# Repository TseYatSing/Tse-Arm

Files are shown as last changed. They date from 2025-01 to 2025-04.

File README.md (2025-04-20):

# Tse-M3CKA
> **我的机械臂**
>
>  视频介绍：[复刻开源机械臂](https://www.bilibili.com/video/BV1GM4m1R7kN/)
> 
>  视频介绍：[打印中](https://v.douyin.com/iyWBaaXT/)
> 
>  视频介绍：[是谁敲了一晚上的代码呀。是我呀累(ノへ`、)](https://v.douyin.com/iyWBVt3w/)
>
>  视频介绍：[上位程序搞定](https://v.douyin.com/aAHZoPsLHYs/)

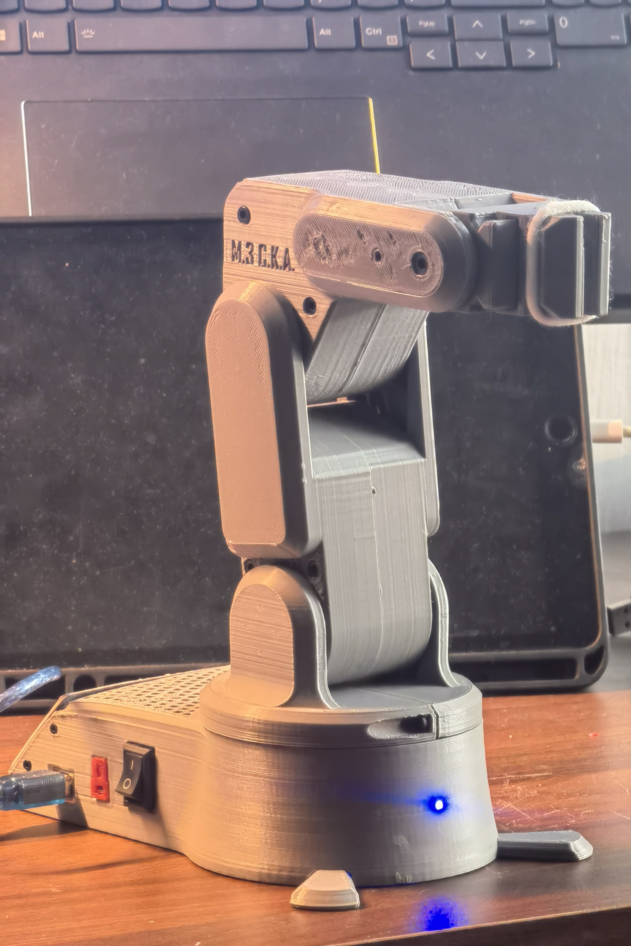
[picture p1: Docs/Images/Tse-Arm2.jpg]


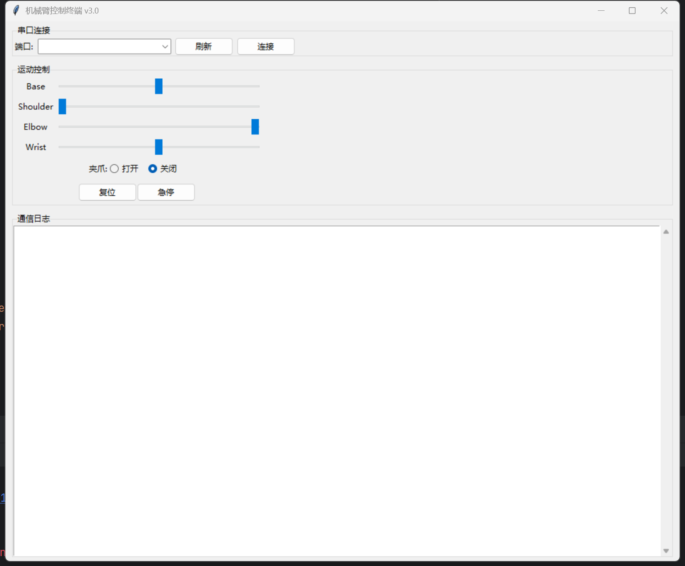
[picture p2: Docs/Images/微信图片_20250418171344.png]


> **感谢以下项目作者：**
>
> * [How to Build a 3D Printed Robot Arm Tutorial (Arduino Based)](https://youtube.com/watch?v=AIsVlgopqJc&si=mFCGv56T8LsnVQlr)

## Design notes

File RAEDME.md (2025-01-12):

# Tse-Arm
> **我的机械臂**
>
> 视频介绍：[【自制】我造了一台 钢 铁 侠 的 机 械 臂 ！【硬核】](https://www.bilibili.com/video/BV12341117rG)
>
> Video : [I made a DUMMY ROBOTIC ARM from scratch！ - YouTube](https://www.youtube.com/watch?v=F29vrvUwqS4)





### 资料说明（更新日期22-2-9）

* 已添加3D模型设计源文件。
* 已添加夹爪硬件设计文件和LED灯环PCB
* 已添加无线空间定位控制器PCB文件
* 已添加无线示教器Peak软硬件工程（作为submodule）
* 已添加REF的硬件设计文件
* 已添加DummyStudio上位机
* 已添加Dummy核心控制器的固件源代码（使用说明见后文）
* 已添加42步进电机驱动器硬件工程
* 已添加20步进电机驱动器硬件工程
* 已添加42/20步进电机驱动的固件源代码
* 已添加命令行调试工具reftool（基于odrivetool框架）
* 已添加便携手提箱的模型文件

> 这是视频中原版机械臂的完整设计方案，该方案成本和制作难度都比较高，因此想复现的同学建议再等等我后面会发布的**Dummy青春版**，该版本会有如下改进：
>
> 1. 整机重新设计结构，改用3D打印作为制造方案（原版为铝CNC），大幅降低制造成本
> 2. 采用我自己设计的小型摆线针轮减速器替代原版的谐波减速器，大幅降低零件成本
> 3. 所有软件和固件和原版通用，功能也完全一致
> 4. 添加我自己设计的PC端上位机和手机端APP（争取把用户初始化设置引导加进去）
> 5. 改进原版电机驱动器的走线方式，原版电源走线采用焊接的形式，不便于安装和拆卸，后面的青春版会使用4p接插件（电源+CAN总线）连接
> 6. 整机成本争取做到2000以内
> 7. **最重要的，会找人出一个保姆级的视频教程！**

## 关于结构设计

我视频中原版设计使用的`步进电机`+Harmonic的`谐波减速模组`，其中后者成本较高（我买的二手大概是600元一个），因此为了能让大家尽量复现本项目，我后期会添加一个`自制摆线针轮减速器`+`3D打印`的低成本方案。

> 目前摆线减速器已经设计好了正在验证，预期会使用PC（或者亚克力）切割结合3D打印制作，精度有所下降但是功能都保持不变，整机硬件成本希望控制在2000元以内。

设计好的摆线减速器见我的另一个仓库：[peng-zhihui/CycloidAcuratorNano ](https://github.com/peng-zhihui/CycloidAcuratorNano)



## 关于电路模块

电路为了实现主要的机械臂运动控制功能其实核心就4块板子：

* REF核心板
* REF底板（也就是机械臂底座里面的控制器电路板）
* 步进电机驱动
* Peak示教器

其中前两者和Peak我都开源了，步进驱动设计的时候参考了： https://github.com/unlir/XDrive 这个项目，这是我一个朋友开源的闭环驱动，基于STM32。该驱动分为开源版和闭源版，闭源版基于分立MOSFET性能极其强劲且功能很完善，开源版用的ADC+斩波驱动芯片，具备基础功能，不带CAN协议。

我重新设计了驱动器的PCB电路（本项目分别用到20、42步进，57的文件只是供大家扩展使用），添加了CAN总线的硬件支持，也对原版核心代码进行了完全重构，**提供编译好的二进制文件可以直接烧录：**



**主要改进如下：**

1. 使用C++11重构了代码，引入很多高级语言特性，同时底层部分用C混编，不影响代码性能
2. 对硬件依赖完全解耦了，可以方便以后移植到其他平台的MCU，去除了冗余代码代码也结构化逻辑更加清晰
3. 添加了CAN协议和UART协议的自定义模板
4. 添加了模拟EEPROM的参数储存，可以断电保存数据
5. 添加了任意位置设置为零点，且保证双向半圈内归零（而不是单向归零）
6. 完全兼容STM32-HAL库，可以使用STM32CubeMX直接生成配置代码
7. 其他改进，大家二次开发仅需关注UserApp文件夹下的文件即可

Ctrl-Step驱动的使用方式比较简单，下载好固件后，第一次上电电机会进行编码器校准，如果成功则下次上电后按下按键1会进入闭环模式，通过CAN或者串口发送指令即可控制电机，关于指令的说明见源代码`UserApp`文件夹的`interface_can.cpp`和`interface_uart.cpp`：



> 其他按键的作用：
>
> * 同时按住两个按键上电，会自动进行编码器校准，如果首次校准失败可以通过这个方式重新校准
> * 短按按键1在**使能闭环/失能闭环**间切换
> * 长按按键1板子重启
> * 短按按键2清除堵转保护
> * 长按按键2将目标值归零（比如如果是在位置模式那位置会归零）
>
> 其他的功能要通过代码或者通信协议设置，比如设置**home零点**、**PID参数**、CAN节点ID、**各种运动参数**等等，可以自己研究代码。

当然另一种方式是大家也可以自行使用GRBL类的驱动器改装用来驱动本机械臂，这样方案的问题在于，grbl固件耦合性比较强（毕竟不是针对机械臂而是CNC类应用设计的）不便于扩展，另外脉冲形式的控制方式使得走线极其不优雅（每一个关节都要单独拉`step/dir`线到控制器，导致最后几个关节走线很长）。

而我用一体闭环的方式则可以以串联的形式把所有电机连起来即可，走CAN总线使得整体走线只需要四根线（电源正负两根，CAN信号线两根），此外总线模型使得电机可以工作在`力矩`、`速度`、`位置`、`轨迹`模式下，而脉冲模式只能工作在位置和轨迹模式，无法进行复杂控制。

**Peak的话我之前已经软硬件都开源了，可以去SubModules文件夹里面看那边的README说明。**

## 关于核心固件

这个机械臂的固件核心就是运动学姿态解算，~~这块我还在整理，后面会封装得更完善一些进行开源~~，**已开源**，现在写死的很多参数会设计成可配置的，**方便大家用本项目学习完后迁移到自己设计的机械臂中**；同时我把固件从LiteOS框架移植到大家更熟悉的FreeRTOS，方便做二次开发。

**REF的固件使用说明：**

固件主要包括几大功能模块：

* BSP驱动：板载的各种硬件驱动比如OLED、IMU、LED、蜂鸣器、非易失储存等等
* 3rdParty库：包括U8G2的图形库和Fibre的序列化/反序列化库
* Core：ST官方的HAL库
* Driver：ARM的CMSIS驱动
* Midwares：FreeRTOS支持包
* Robot：核心机器人库，包括各种算法和驱动代码
* UserApp：上层应用，可以基于我提供的API接口自行开发其他应用

> * 其中OLED使用Arduino的U8G2库移植而来，可以方便地现实各种调试和系统信息，另外由于STM32的硬件I2C又BUG这里使用了软件I2C驱动屏幕，实测帧率比硬件I2C更高。

`DummyRobot`类是Dummy的完整定义所在，初始化的时候需要设置好**步进电机驱动的信息**以及**自身的DH参数**：



其中驱动器信息包含：CAN节点ID、**是否反向**、减速器的减速比、**运动限制范围**。

而DH参数的含义如下：



机械臂的构型需要满足Pieper判据（机器人的三个相邻关节轴交于一点或三轴线平行），才能得出解析解，所以大家可以根据Dummy的结构进行修改，然后自己替换DH参数即可以移植我的代码。

> 关于位置的记忆，和上电零点校准：
>
> **由于绝对值编码器的位置只在一圈内有效，工业机械臂经过减速后为了获取绝对位置一般是做输出端编码，但是这样精度就降低了30倍（减速比），所以更合理的是做`双编码器`或者低`功耗编码器+电池`；而我这个项目中双编码器影响结构紧凑设计，所以用了更巧妙的方式：利用电机驱动的电流环控制上电后进行低力矩的无零点定向运动，碰到机械臂限位之后确认粗零点（无限位开关归零），然后根据单圈绝对值编码器的位置精调零点。这个方式的零点是没有误差的，而且几乎不受加工精度影响，因为在12度（360/30）内都是绝对值编码器的有效精度范围。**

**Peak的固件说明：**

Peak基于X-Track项目，大家可以去Peak仓库查看。

## 关于上位机

视频中的软件仿真基于RoboDK，我在视频中开发了连接Dummy的Driver（驱动部分官方document有介绍的，原版是基于TCP网络接口，我修改成了串口并兼容dummy的协议）。不过由于这个软件是收费的，因此我也基于Unity3D开发了自己的上位机，已经发布在仓库。

上位机目前暂时没有计划开源，因为还有很多功能要添加，我也是希望最后能做成一个类似RoboDK的通用软件，大家以后自己做机械臂也能用上，当然软件肯定会是免费的。

## 关于控制算法

首先运动学部分是已经实现了的，正逆解都是传统DH参数计算的，正解（关节角求末端位姿）是唯一解比较好办，逆解（末端位姿求关节角）的话会涉及多解（一般是8个），我这里使用的算法是**求解上一姿态和目标姿态中6个关节变化最大角里面最小的那一组作为逆解采用的config**。这样可以保证机械臂始终以最小转角进行姿态切换。

然后关节角到电机驱动器输入信号的转换这一块，我使用的是梯形加减速曲线进行速度位置规划。举个例子在MoveJ指令中，当收到一个关节角运动指令，控制器会进行运动角度差分计算，得到6个运动差分角度，然后取6个差分角中最大的角θ，同时根据设置的JointSpeed参数计算运动θ角需要的时间（考虑上加减速），把这一时间作为其余5个电机的运动参数计算各自的加减速度&最高速度，然后6个电机根据计算的参数同步运动，就可以保证其同步性和流畅性了。

另外六个电机使用CAN总线连接，每个电机接受两个ID号的信息（自己的ID、0号ID），0号ID作为信息广播和同步用。电机接收到运动指令后将信息储存在影子寄存器中，待收到广播的同步信号后开始运动，这样能进一步保证电机同步性。

最后，动力学部分还在开发中，这块暂时没有完全实现。上**述的运动学和动力学算法都强烈建议去看一下《机器人学导论》这本书**，里面写得非常详细。

## 指令模式

Dummy固件支持三种不同的指令模式（指令可以由USB、串口、CAN接收），不同模式的特性有所区别，见下表：

| | 指令发送频率 | 指令执行方式 | 可被新指令打断 | 指令间停顿 | 适合场景 |
| --- | --- | --- | --- | --- | --- |
| SEQ（顺序指令） | 随机，低（<5Hz）  | FIFO队列依次执行 | 否 | 有 | 一次性发送几个关键点位姿，等待依次执行，可以确保关键点到达；但是由于关键点之间存在减速到0的过程所以存在一定停顿；适合场景例如**视觉抓取、码垛等应用**。 |
| INT（实时指令） | 随机，频率不限 | 指令覆盖，立即执行 | 是 | 无 | 用于实时控制，新指令会覆盖正在执行的指令得到立即响应；但是如果一次性发送一系列指令的话则效果会是只执行最后一条；适合场景例如**动作同步**。 |
| `ToDo`TRJ（轨迹跟踪） | 固定，高（200Hz） | 自动插值，固定周期执行 | 否 | 无 | 适合用于需要进行精确轨迹跟踪的应用，速度会放慢；示例场景比如**3D打印、雕刻、绘画等**。 |

---

> **感谢以下项目作者：**
>
> * [unlir/XDrive: Stepper motor with multi-function interface and closed loop function. 具有多功能接口和闭环功能的步进电机。 (github.com)](https://github.com/unlir/XDrive)

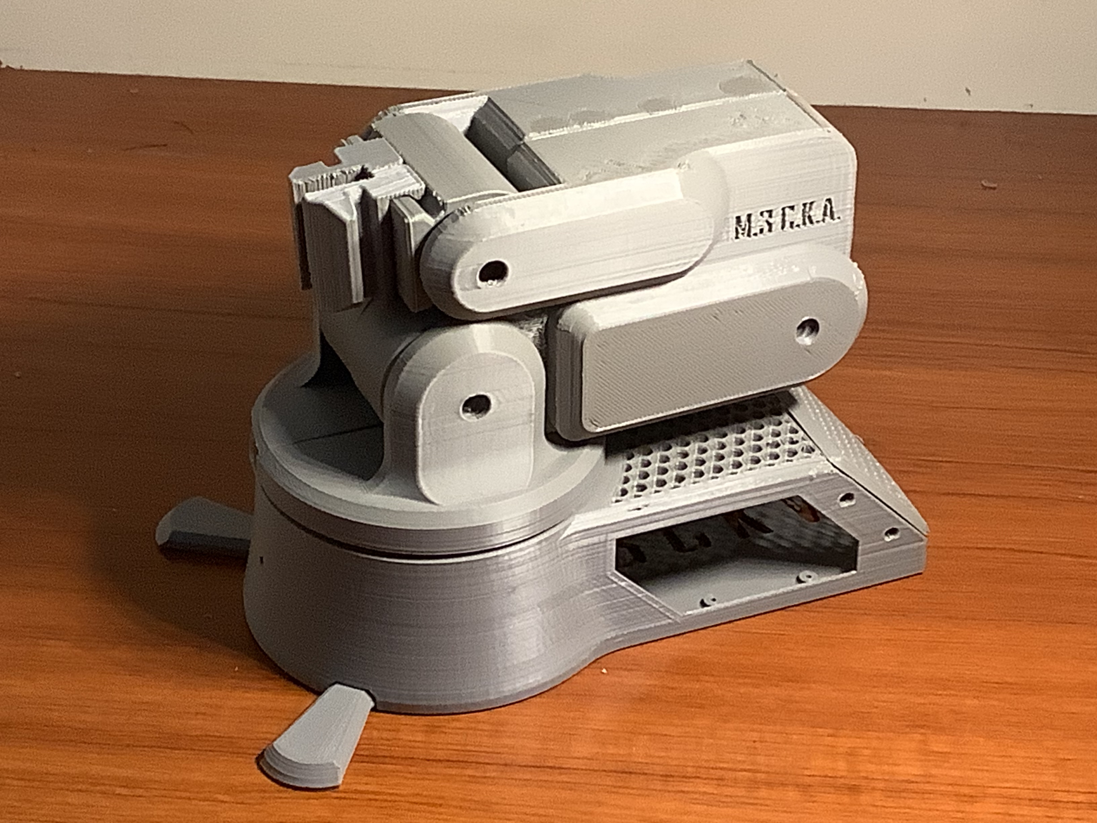
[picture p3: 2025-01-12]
Docs/Images/Tse-Arm1.jpg

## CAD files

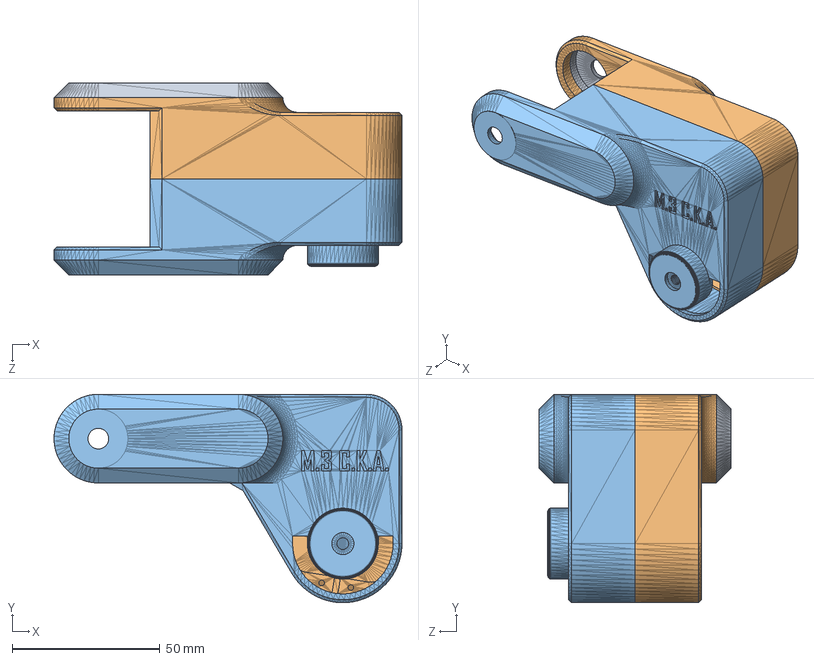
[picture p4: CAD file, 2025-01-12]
Model/F/F.SLDASM
117.7 x 70.5 x 65.1 mm
F1
F2
F2C

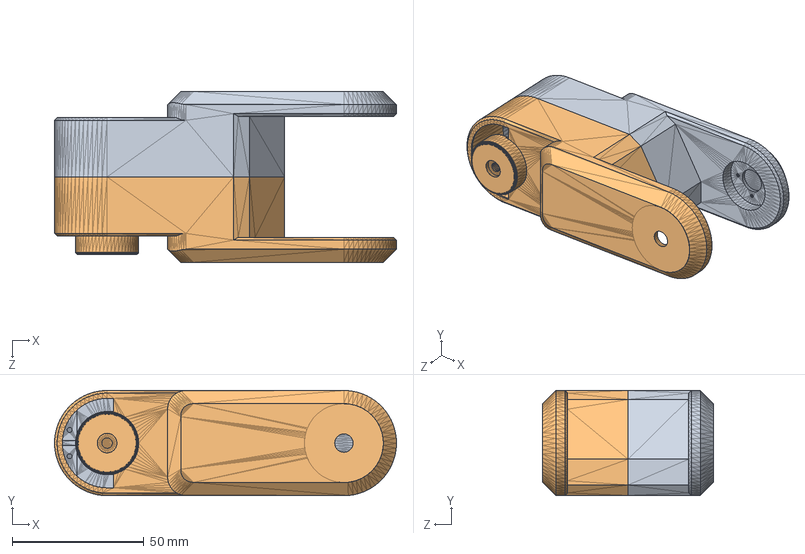
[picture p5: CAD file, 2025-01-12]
Model/M/M.SLDASM
130.0 x 39.9 x 65.1 mm
M1
M2

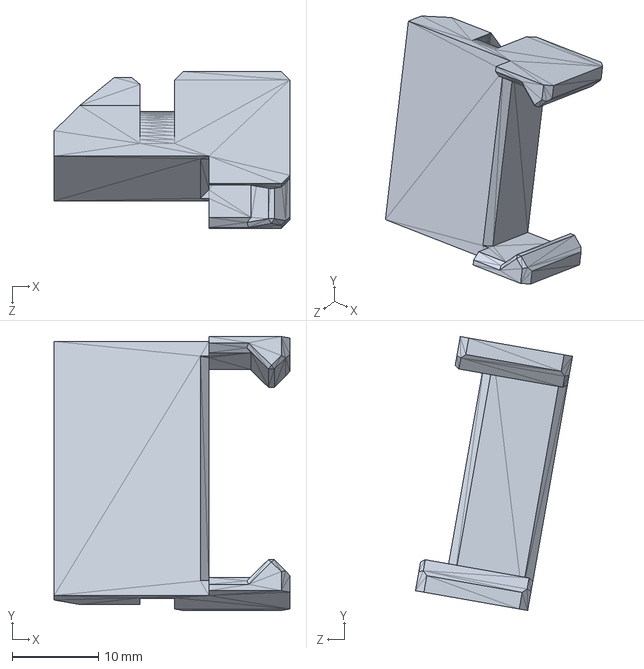
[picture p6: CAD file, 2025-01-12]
Model/G/G3.SLDPRT
27.4 x 31.8 x 18.3 mm

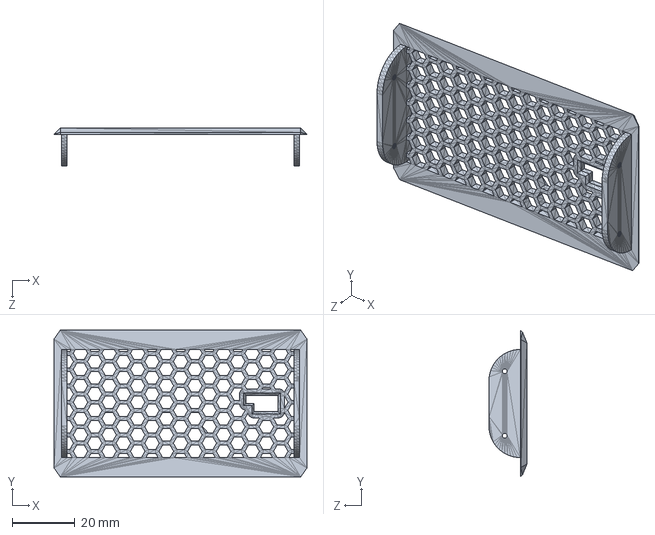
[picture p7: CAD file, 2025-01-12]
Model/MB/MB4.SLDPRT
80.5 x 46.7 x 12.1 mm

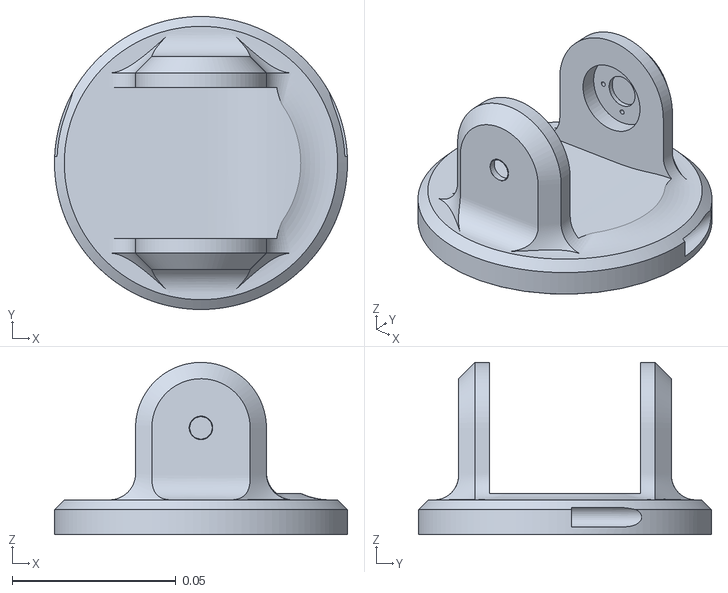
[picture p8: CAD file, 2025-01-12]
Model/URDF/robot arm.SLDASM/meshes/B_Link.STL
0.0895 x 0.0895 x 0.0526

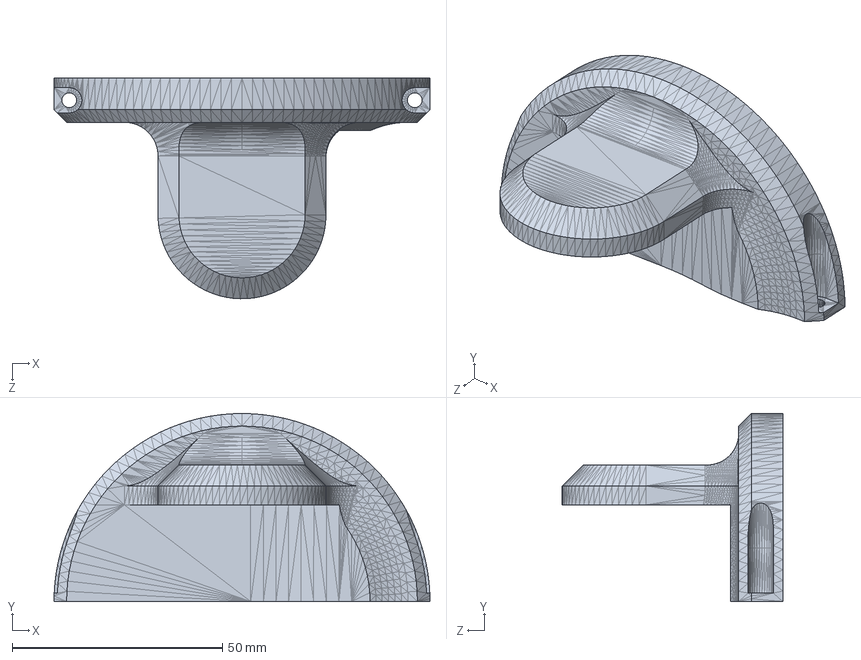
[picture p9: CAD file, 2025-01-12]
Model/B/B (2).SLDPRT
89.5 x 44.8 x 52.5 mm

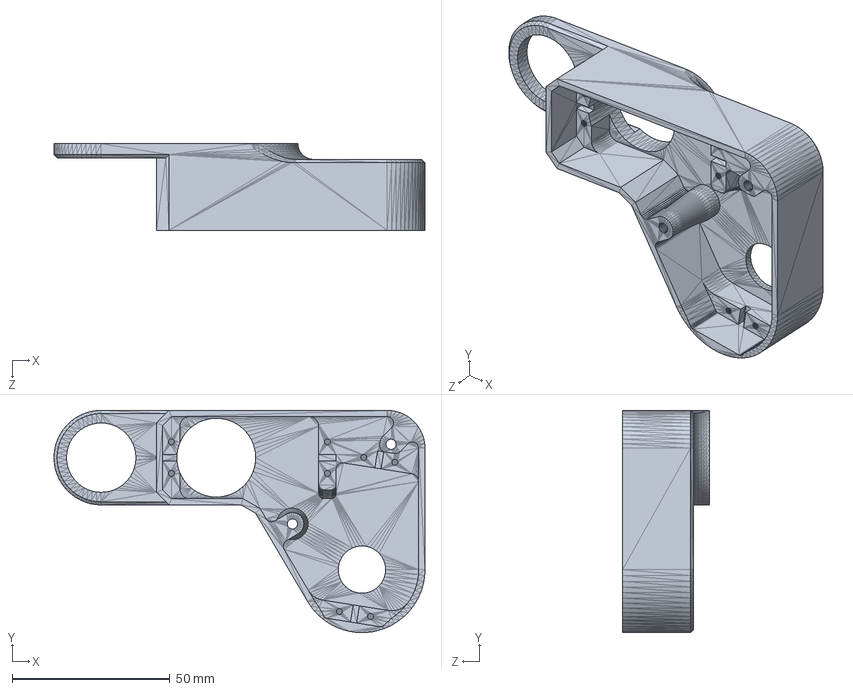
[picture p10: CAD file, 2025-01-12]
Model/F/F2.SLDPRT
117.7 x 70.5 x 27.5 mm

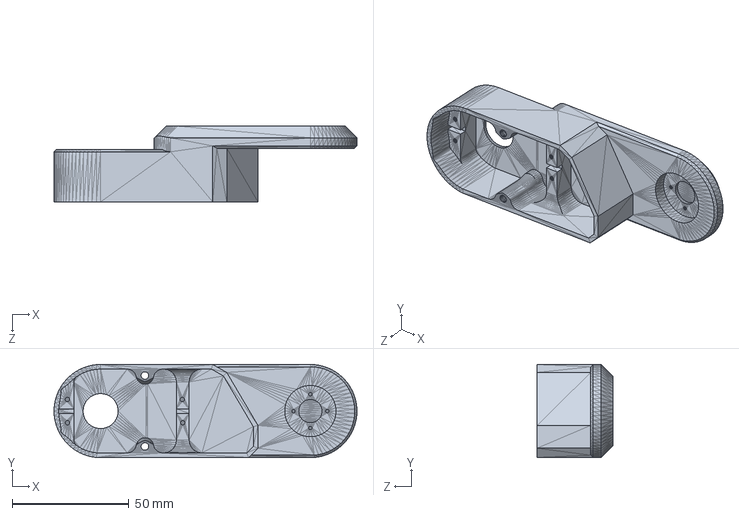
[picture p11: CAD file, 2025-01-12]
Model/M/M2.SLDPRT
130.0 x 39.9 x 32.5 mm

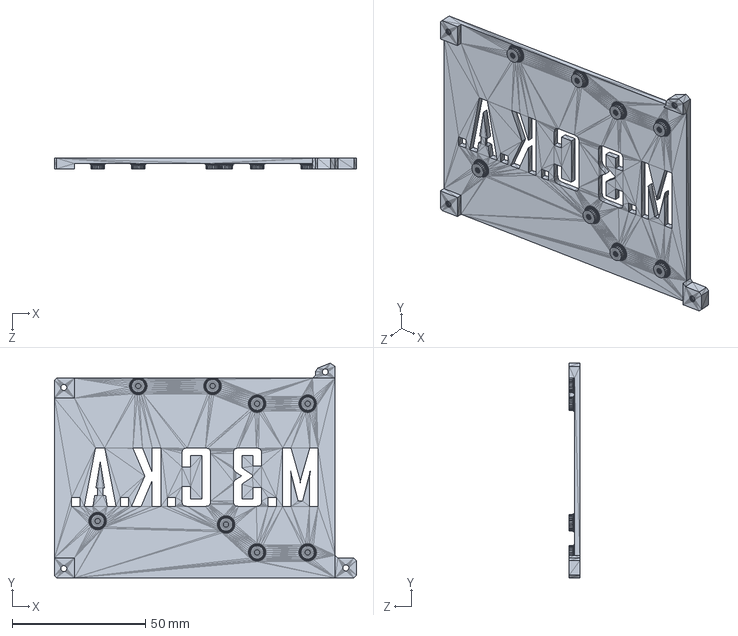
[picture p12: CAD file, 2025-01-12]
Model/MB/MB2.SLDPRT
113.5 x 80.7 x 4.00 mm

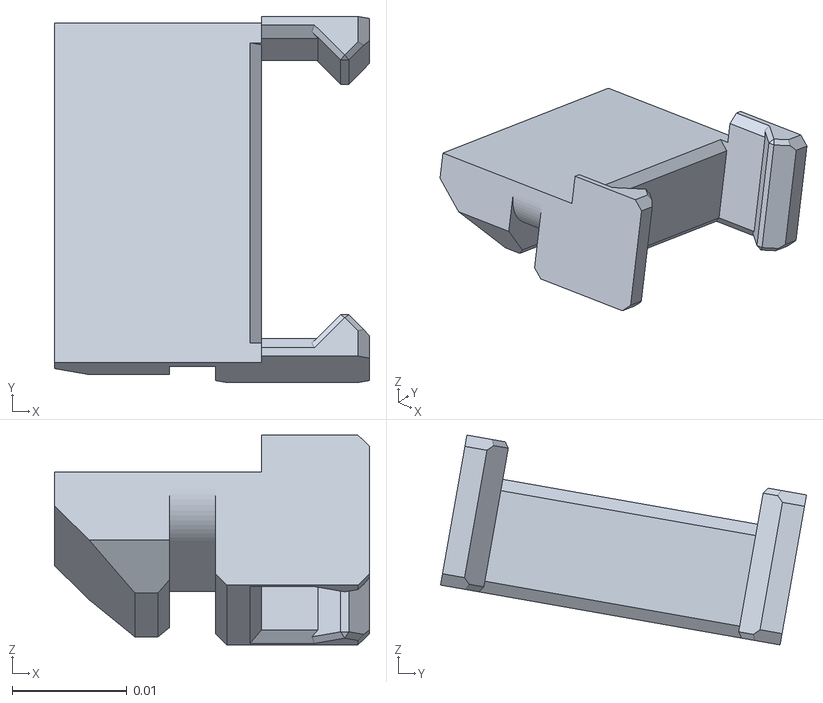
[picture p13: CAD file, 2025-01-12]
Model/URDF/robot arm.SLDASM/meshes/HR_Link.STL
0.0274 x 0.0318 x 0.0183

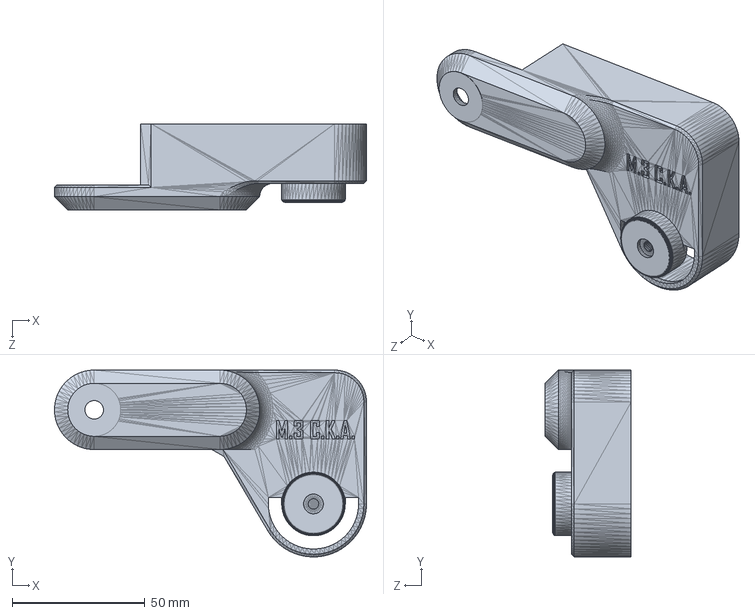
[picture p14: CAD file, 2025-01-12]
Model/F/F1.SLDPRT
117.7 x 70.5 x 32.6 mm

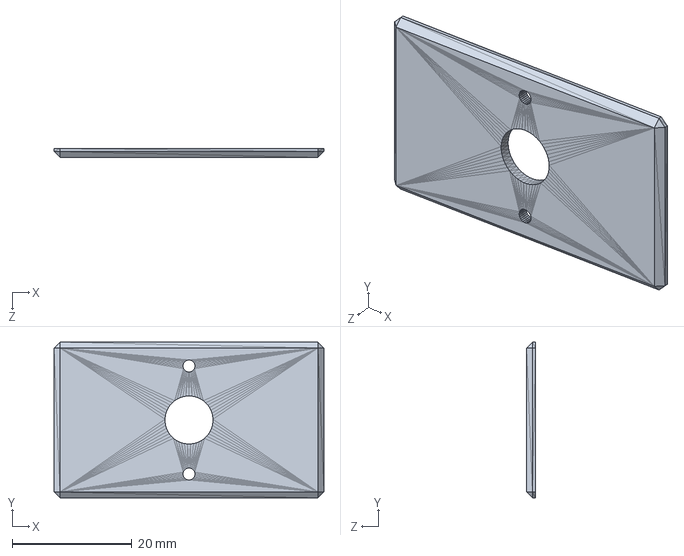
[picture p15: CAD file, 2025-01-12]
Model/G/G2.SLDPRT
45.0 x 26.0 x 1.50 mm

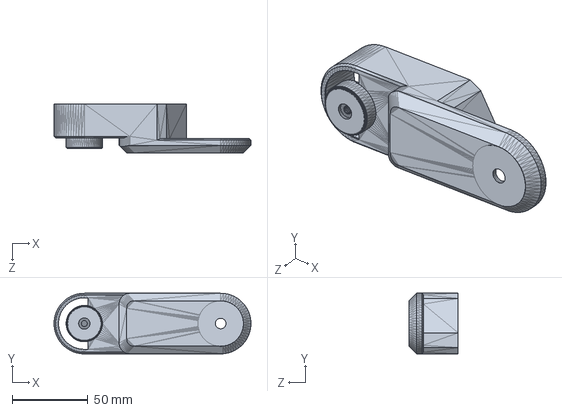
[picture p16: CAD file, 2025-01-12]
Model/M/M1.SLDPRT
130.0 x 39.9 x 32.6 mm

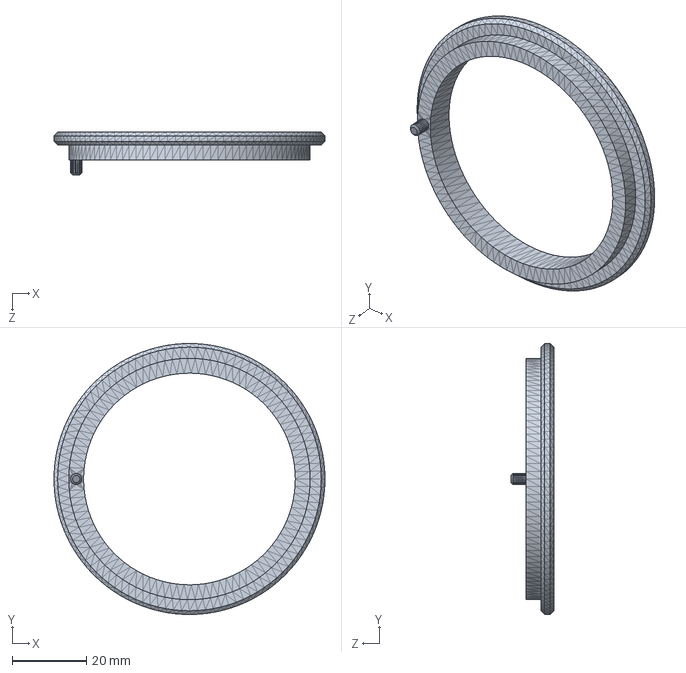
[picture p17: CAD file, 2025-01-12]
Model/MB/MB1R.SLDPRT
73.0 x 73.0 x 11.5 mm

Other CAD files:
Model/B/B (1).SLDASM
Model/G/G.SLDASM
Model/URDF/robot arm.SLDASM/meshes/S_Link.STL
Model/F/F2C.SLDPRT
Model/G/G1.SLDPRT
Model/G/G4.SLDPRT
Model/MB/MB3.SLDPRT
Model/URDF/robot arm.SLDASM/meshes/E_Link.STL
Model/URDF/robot arm.SLDASM/meshes/HL_Link.STL
Model/URDF/robot arm.SLDASM/meshes/W_Link.STL
Model/URDF/robot arm.SLDASM/meshes/base_link.STL

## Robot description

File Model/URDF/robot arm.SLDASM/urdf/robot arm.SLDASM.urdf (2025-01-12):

<?xml version="1.0" encoding="utf-8"?>
<!-- This URDF was automatically created by SolidWorks to URDF Exporter! Originally created by Stephen Brawner (brawner@gmail.com) 
     Commit Version: 1.6.0-4-g7f85cfe  Build Version: 1.6.7995.38578
     For more information, please see http://wiki.ros.org/sw_urdf_exporter -->
<robot name="robot arm.SLDASM">
  <link name="base_link">
    <inertial>
      <origin xyz="0.038474 0.047626 0.066497" rpy="0 0 0" />
      <mass value="0.014181" />
      <inertia ixx="5.6168E-06" ixy="-1.2686E-09" ixz="1.085E-09" iyy="1.3583E-05" iyz="-4.3104E-07" izz="8.9876E-06" />
    </inertial>
    <visual>
      <origin xyz="0 0 0" rpy="0 0 0" />
      <geometry>
        <mesh filename="package://robot arm.SLDASM/meshes/base_link.STL" />
      </geometry>
      <material name="">
        <color rgba="0.79216 0.81961 0.93333 1" />
      </material>
    </visual>
    <collision>
      <origin xyz="0 0 0" rpy="0 0 0" />
      <geometry>
        <mesh filename="package://robot arm.SLDASM/meshes/base_link.STL" />
      </geometry>
    </collision>
  </link>
  <link name="B_Link">
    <inertial>
      <origin xyz="0.00061683 0.0022099 0.013874" rpy="0 0 0" />
      <mass value="0.055527" />
      <inertia ixx="1.6319E-05" ixy="2.4099E-08" ixz="8.2856E-08" iyy="3.3446E-05" iyz="4.9691E-09" izz="3.086E-05" />
    </inertial>
    <visual>
      <origin xyz="0 0 0" rpy="0 0 0" />
      <geometry>
        <mesh filename="package://robot arm.SLDASM/meshes/B_Link.STL" />
      </geometry>
      <material name="">
        <color rgba="0.79216 0.81961 0.93333 1" />
      </material>
    </visual>
    <collision>
      <origin xyz="0 0 0" rpy="0 0 0" />
      <geometry>
        <mesh filename="package://robot arm.SLDASM/meshes/B_Link.STL" />
      </geometry>
    </collision>
  </link>
  <joint name="BJ" type="revolute">
    <origin xyz="0.038382 -0.10676 0.051092" rpy="0 0 1.5658" />
    <parent link="base_link" />
    <child link="B_Link" />
    <axis xyz="0 0 -1" />
    <limit lower="-1.57" upper="1.57" effort="100" velocity="2.01" />
  </joint>
  <link name="S_Link">
    <inertial>
      <origin xyz="0.064577 -0.0006428 -0.0044202" rpy="0 0 0" />
      <mass value="0.074894" />
      <inertia ixx="1.7741E-05" ixy="5.6338E-07" ixz="2.0818E-06" iyy="8.194E-05" iyz="1.0703E-08" izz="8.883E-05" />
    </inertial>
    <visual>
      <origin xyz="0 0 0" rpy="0 0 0" />
      <geometry>
        <mesh filename="package://robot arm.SLDASM/meshes/S_Link.STL" />
      </geometry>
      <material name="">
        <color rgba="0.79216 0.81961 0.93333 1" />
      </material>
    </visual>
    <collision>
      <origin xyz="0 0 0" rpy="0 0 0" />
      <geometry>
        <mesh filename="package://robot arm.SLDASM/meshes/S_Link.STL" />
      </geometry>
    </collision>
  </link>
  <joint name="SJ" type="revolute">
    <origin xyz="0.038382 -0.10676 0.063392" rpy="-1.5708 -1.5557 -1.5758" />
    <parent link="base_link" />
    <child link="S_Link" />
    <axis xyz="0 0 1" />
    <limit lower="-1.57" upper="1.57" effort="100" velocity="2.01" />
  </joint>
  <link name="E_Link">
    <inertial>
      <origin xyz="0.073989 0.047337 -0.017744" rpy="0 0 0" />
      <mass value="0.036475" />
      <inertia ixx="1.4964E-05" ixy="4.7351E-06" ixz="-1.6026E-06" iyy="3.0336E-05" iyz="4.1041E-07" izz="4.2075E-05" />
    </inertial>
    <visual>
      <origin xyz="0 0 0" rpy="0 0 0" />
      <geometry>
        <mesh filename="package://robot arm.SLDASM/meshes/E_Link.STL" />
      </geometry>
      <material name="">
        <color rgba="0.79216 0.81961 0.93333 1" />
      </material>
    </visual>
    <collision>
      <origin xyz="0 0 0" rpy="0 0 0" />
      <geometry>
        <mesh filename="package://robot arm.SLDASM/meshes/E_Link.STL" />
      </geometry>
    </collision>
  </link>
  <joint name="EJ" type="revolute">
    <origin xyz="0.03889 -0.20556 0.1525" rpy="1.5708 -0.012159 1.5658" />
    <parent link="base_link" />
    <child link="E_Link" />
    <axis xyz="0 0 0" />
    <limit lower="-1.57" upper="1.57" effort="100" velocity="2.01" />
  </joint>
  <link name="W_Link">
    <inertial>
      <origin xyz="0.023273 0.013 -0.014326" rpy="0 0 0" />
      <mass value="0.027884" />
      <inertia ixx="3.9584E-06" ixy="4.4613E-13" ixz="-4.748E-07" iyy="8.9096E-06" iyz="-3.5765E-13" izz="9.2469E-06" />
    </inertial>
    <visual>
      <origin xyz="0 0 0" rpy="0 0 0" />
      <geometry>
        <mesh filename="package://robot arm.SLDASM/meshes/W_Link.STL" />
      </geometry>
      <material name="">
        <color rgba="0.79216 0.81961 0.93333 1" />
      </material>
    </visual>
    <collision>
      <origin xyz="0 0 0" rpy="0 0 0" />
      <geometry>
        <mesh filename="package://robot arm.SLDASM/meshes/W_Link.STL" />
      </geometry>
    </collision>
  </link>
  <joint name="WJ" type="fixed">
    <origin xyz="0.01688 -0.2075 0.19376" rpy="1.6544 0 -0.0049831" />
    <parent link="base_link" />
    <child link="W_Link" />
    <axis xyz="0 0 0" />
    <limit lower="-1.57" upper="1.57" effort="100" velocity="2.01" />
  </joint>
  <link name="HL_Link">
    <inertial>
      <origin xyz="0.011436 0.015 0.0060195" rpy="0 0 0" />
      <mass value="0.004589" />
      <inertia ixx="4.3212E-07" ixy="6.3465E-15" ixz="5.8852E-09" iyy="2.305E-07" iyz="2.4915E-15" izz="5.9215E-07" />
    </inertial>
    <visual>
      <origin xyz="0 0 0" rpy="0 0 0" />
      <geometry>
        <mesh filename="package://robot arm.SLDASM/meshes/HL_Link.STL" />
      </geometry>
      <material name="">
        <color rgba="0.79216 0.81961 0.93333 1" />
      </material>
    </visual>
    <collision>
      <origin xyz="0 0 0" rpy="0 0 0" />
      <geometry>
        <mesh filename="package://robot arm.SLDASM/meshes/HL_Link.STL" />
      </geometry>
    </collision>
  </link>
  <joint name="HLJ" type="prismatic">
    <origin xyz="0.054975 -0.22936 0.22004" rpy="-1.5708 -0.083571 1.5658" />
    <parent link="base_link" />
    <child link="HL_Link" />
    <axis xyz="0 0 0" />
    <limit lower="0" upper="0.02" effort="100" velocity="2.01" />
  </joint>
  <link name="HR_Link">
    <inertial>
      <origin xyz="0.011436 0.015817 0.0085328" rpy="0 0 0" />
      <mass value="0.004589" />
      <inertia ixx="4.3212E-07" ixy="1.022E-09" ixz="5.7958E-09" iyy="2.4141E-07" iyz="6.1845E-08" izz="5.8124E-07" />
    </inertial>
    <visual>
      <origin xyz="0 0 0" rpy="0 0 0" />
      <geometry>
        <mesh filename="package://robot arm.SLDASM/meshes/HR_Link.STL" />
      </geometry>
      <material name="">
        <color rgba="0.79216 0.81961 0.93333 1" />
      </material>
    </visual>
    <collision>
      <origin xyz="0 0 0" rpy="0 0 0" />
      <geometry>
        <mesh filename="package://robot arm.SLDASM/meshes/HR_Link.STL" />
      </geometry>
    </collision>
  </link>
  <joint name="HRJ" type="prismatic">
    <origin xyz="0.018549 -0.22675 0.19105" rpy="1.7453 -0.083571 1.5658" />
    <parent link="base_link" />
    <child link="HR_Link" />
    <axis xyz="0 0 0" />
    <limit lower="-0.02" upper="0" effort="100" velocity="2.01" />
  </joint>
</robot>

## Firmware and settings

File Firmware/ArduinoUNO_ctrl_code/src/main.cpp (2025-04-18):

#include <Arduino.h>
#include <Adafruit_PWMServoDriver.h>

#define MIN_PULSE_WIDTH   500
#define MAX_PULSE_WIDTH   2500
#define PWM_FREQ          50
#define MAX_CMD_LENGTH    30

Adafruit_PWMServoDriver pwm = Adafruit_PWMServoDriver();

const uint8_t SERVO_PINS[5] = {15, 14, 13, 12, 11}; // BASE, SHOULDER, ELBOW, WRIST, GRIPPER

float angleToPulse(float angle) {
  angle = constrain(angle, 0.0, 180.0);
  return map(angle, 0.0, 180.0, MIN_PULSE_WIDTH, MAX_PULSE_WIDTH);
}

void setServoAngle(uint8_t servoPin, float angle) {
  pwm.writeMicroseconds(servoPin, angleToPulse(angle));
  
  Serial.print("Servo[");
  Serial.print(servoPin);
  Serial.print("] ");
  Serial.print(angle);
  Serial.println("°");
}

void moveArm(float angles[4], bool gripperOpen) {
  for(int i=0; i<4; i++){
    setServoAngle(SERVO_PINS[i], angles[i]);
  }
  setServoAngle(SERVO_PINS[4], gripperOpen ? 90 : 0);
  Serial.println("OK");
}

bool validateAngles(float angles[4]) {
  for(int i=0; i<4; i++){
    if(angles[i] < 0 || angles[i] > 180) return false;
  }
  return true;
}

void processCommand(String input) {
  if(input.length() == 0) return;

  // 格式验证
  int spaceIndex = input.indexOf(' ');
  if(spaceIndex == -1 || input.substring(spaceIndex+1).length() == 0){
    Serial.println("ERROR:INVALID_FORMAT");
    return;
  }

  // 分割角度和状态
  String anglePart = input.substring(0, spaceIndex);
  String statePart = input.substring(spaceIndex+1);

  // 解析角度
  float angles[4];
  int commaPos[3];
  int commaCount = 0;
  
  for(int i=0; i<anglePart.length() && commaCount<3; i++){
    if(anglePart[i] == ','){
      if(commaCount < 3) commaPos[commaCount] = i;
      commaCount++;
    }
  }

  if(commaCount != 3){
    Serial.println("ERROR:ANGLE_FORMAT");
    return;
  }

  angles[0] = anglePart.substring(0, commaPos[0]).toFloat();
  angles[1] = anglePart.substring(commaPos[0]+1, commaPos[1]).toFloat();
  angles[2] = anglePart.substring(commaPos[1]+1, commaPos[2]).toFloat();
  angles[3] = anglePart.substring(commaPos[2]+1).toFloat();

  // 验证角度
  if(!validateAngles(angles)){
    Serial.println("ERROR:ANGLE_RANGE");
    return;
  }

  // 解析状态
  statePart.toLowerCase();
  bool gripper = (statePart == "on" || statePart == "1");

  moveArm(angles, gripper);
}

void setup() {
  Serial.begin(115200);
  pwm.begin();
  pwm.setPWMFreq(PWM_FREQ);
  Serial.println("READY");
}

void loop() {
  static String inputBuffer = "";
  
  while(Serial.available() > 0){
    char c = Serial.read();
    
    if(c == '\n'){
      inputBuffer.trim();
      processCommand(inputBuffer);
      inputBuffer = "";
    }else if(inputBuffer.length() < MAX_CMD_LENGTH){
      inputBuffer += c;
    }else{
      Serial.println("ERROR:CMD_TOO_LONG");
      inputBuffer = "";
      while(Serial.available()) Serial.read(); // 清空缓冲区
    }
  }
}

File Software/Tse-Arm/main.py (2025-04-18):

import tkinter as tk
from tkinter import ttk, scrolledtext
import serial
import serial.tools.list_ports
from threading import Thread, Event
import queue
import time


class RoboticArmApp:
    def __init__(self, master):
        self.master = master
        master.title("机械臂控制终端 v3.0")
        master.geometry("1000x800")

        # 通信配置
        self.serial_port = None
        self.serial_queue = queue.Queue()
        self.cmd_queue = queue.Queue()
        self.running = Event()
        self.running.set()
        self.last_send = 0
        self.send_interval = 0.12  # 120ms

        # 初始化UI
        self.create_widgets()

        # 启动工作线程
        Thread(target=self.read_serial, daemon=True).start()
        Thread(target=self.process_queue, daemon=True).start()

    def create_widgets(self):
        # 串口控制区域
        conn_frame = ttk.LabelFrame(self.master, text="串口连接")
        conn_frame.grid(row=0, column=0, padx=10, pady=5, sticky="ew")

        ttk.Label(conn_frame, text="端口:").grid(row=0, column=0)
        self.port_combo = ttk.Combobox(conn_frame, width=25)
        self.port_combo.grid(row=0, column=1, padx=5)

        ttk.Button(conn_frame, text="刷新", command=self.refresh_ports).grid(row=0, column=2)
        self.connect_btn = ttk.Button(conn_frame, text="连接", command=self.toggle_connection)
        self.connect_btn.grid(row=0, column=3, padx=5)

        # 机械臂控制区域
        ctrl_frame = ttk.LabelFrame(self.master, text="运动控制")
        ctrl_frame.grid(row=1, column=0, padx=10, pady=5, sticky="ew")

        self.sliders = {}
        joints = [
            ('Base', 90, 0, 180),
            ('Shoulder', 0, 0, 180),
            ('Elbow', 180, 0, 180),
            ('Wrist', 90, 0, 180)
        ]
        for idx, (name, init, minv, maxv) in enumerate(joints):
            ttk.Label(ctrl_frame, text=name).grid(row=idx, column=0, padx=5)
            slider = ttk.Scale(ctrl_frame, from_=minv, to=maxv,
                               orient=tk.HORIZONTAL, length=300,
                               command=lambda v, n=name: self.on_slider_change(n, v))
            slider.set(init)
            slider.grid(row=idx, column=1, pady=2)
            self.sliders[name] = slider

        # 夹爪控制
        self.gripper_var = tk.BooleanVar()
        grip_frame = ttk.Frame(ctrl_frame)
        grip_frame.grid(row=4, columnspan=2, pady=5)
        ttk.Label(grip_frame, text="夹爪:").pack(side=tk.LEFT)
        ttk.Radiobutton(grip_frame, text="打开", variable=self.gripper_var,
                        value=True, command=self.queue_command).pack(side=tk.LEFT)
        ttk.Radiobutton(grip_frame, text="关闭", variable=self.gripper_var,
                        value=False, command=self.queue_command).pack(side=tk.LEFT, padx=10)

        # 系统控制
        btn_frame = ttk.Frame(ctrl_frame)
        btn_frame.grid(row=5, columnspan=2, pady=5)
        ttk.Button(btn_frame, text="复位", command=self.reset).pack(side=tk.LEFT)
        ttk.Button(btn_frame, text="急停", command=self.emergency_stop).pack(side=tk.LEFT)

        # 日志区域
        log_frame = ttk.LabelFrame(self.master, text="通信日志")
        log_frame.grid(row=2, column=0, padx=10, pady=5, sticky="nsew")

        self.log_text = scrolledtext.ScrolledText(log_frame, wrap=tk.WORD,
                                                  height=15, font=('Consolas', 10))
        self.log_text.pack(fill=tk.BOTH, expand=True)

        # 布局配置
        self.master.columnconfigure(0, weight=1)
        self.master.rowconfigure(2, weight=1)

        self.refresh_ports()

    def refresh_ports(self):
        ports = [p.device for p in serial.tools.list_ports.comports()]
        self.port_combo['values'] = ports
        if ports:
            self.port_combo.current(0)

    def toggle_connection(self):
        if self.serial_port and self.serial_port.is_open:
            self.disconnect()
        else:
            self.connect()

    def connect(self):
        try:
            self.serial_port = serial.Serial(
                port=self.port_combo.get(),
                baudrate=115200,
                timeout=1,
                write_timeout=1
            )
            self.connect_btn.config(text="断开")
            self.log("连接成功")
        except Exception as e:
            self.log(f"连接失败: {str(e)}")

    def disconnect(self):
        if self.serial_port:
            self.serial_port.close()
            self.connect_btn.config(text="连接")
            self.log("已断开连接")

    def on_slider_change(self, name, value):
        self.queue_command()

    def queue_command(self):
        angles = [int(round(self.sliders[n].get())) for n in ['Base', 'Shoulder', 'Elbow', 'Wrist']]
        state = 'on' if self.gripper_var.get() else 'off'
        cmd = f"{angles[0]},{angles[1]},{angles[2]},{angles[3]} {state}"
        self.cmd_queue.put(cmd)

    def process_queue(self):
        while self.running.is_set():
            if not self.serial_port or not self.serial_port.is_open:
                time.sleep(0.1)
                continue

            try:
                # 流量控制
                if time.time() - self.last_send < self.send_interval:
                    time.sleep(0.01)
                    continue

                cmd = self.cmd_queue.get_nowait()
                full_cmd = cmd + '\n'
                self.serial_port.write(full_cmd.encode())
                self.last_send = time.time()
                self.log(f">> {cmd}")
            except queue.Empty:
                time.sleep(0.01)
            except Exception as e:
                self.log(f"发送错误: {str(e)}")

    def reset(self):
        for name, val in [('Base', 90), ('Shoulder', 0), ('Elbow', 180), ('Wrist', 90)]:
            self.sliders[name].set(val)
        self.gripper_var.set(False)
        self.queue_command()

    def emergency_stop(self):
        self.cmd_queue.queue.clear()
        self.serial_port.write(b"90,0,180,90 off\n")
        self.reset()
        self.log("! 急停已触发")

    def read_serial(self):
        while self.running.is_set():
            if not self.serial_port or not self.serial_port.is_open:
                time.sleep(0.1)
                continue

            try:
                line = self.serial_port.readline().decode(errors='ignore').strip()
                if line:
                    self.serial_queue.put(line)
                    self.master.after(10, self.update_log)
            except Exception as e:
                self.log(f"读取错误: {str(e)}")

    def update_log(self):
        while not self.serial_queue.empty():
            msg = self.serial_queue.get()
            self.log(f"<< {msg}")

    def log(self, message):
        self.log_text.insert(tk.END, message + '\n')
        self.log_text.see(tk.END)

    def on_close(self):
        self.running.clear()
        self.disconnect()
        self.master.destroy()


if __name__ == "__main__":
    root = tk.Tk()
    app = RoboticArmApp(root)
    root.protocol("WM_DELETE_WINDOW", app.on_close)
    root.mainloop()

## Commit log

2025-01-12 第一次提交
    [B (1).SLDASM, B (2).SLDPRT, B_Link.STL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]
2025-01-12 更改错误
2025-01-12 更改了read文件
2025-04-18 改bug
